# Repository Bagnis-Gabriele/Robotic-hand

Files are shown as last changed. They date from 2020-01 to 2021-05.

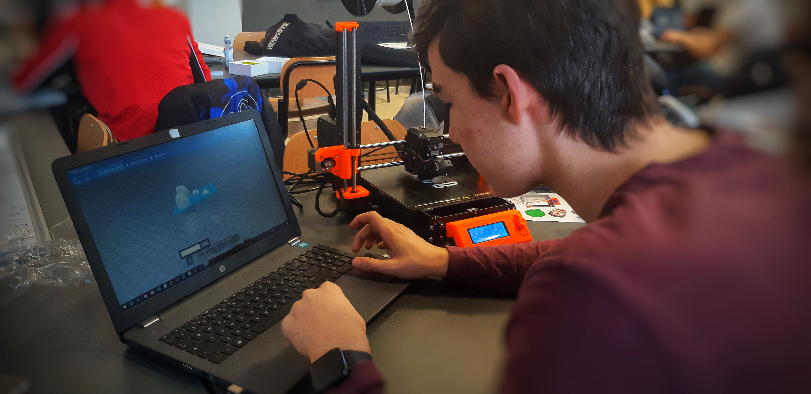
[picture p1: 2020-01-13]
photos/Team/Genovese.JPG

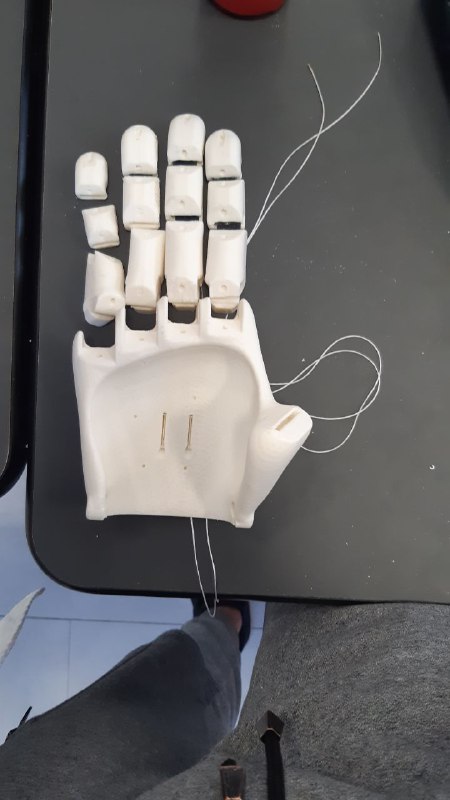
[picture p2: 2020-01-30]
photos/schemes/hand(no_thumb).jpg

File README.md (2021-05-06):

# Robotic-hand

### Project of Bagnis Gabriele, Bruno Luca, Cuniberti Andrea, Genovese Tommaso and Giavelli Luca.

* ### [Our Project](https://github.com/Bagnis-Gabriele/Robotic-hand/wiki/Our-Project#our-project)
* ### [Our Team](https://github.com/Bagnis-Gabriele/Robotic-hand/wiki/Our-Team#our-team)
* ### [Robotic Hand](https://github.com/Bagnis-Gabriele/Robotic-hand/wiki/The-Hand)
* ### [The Programs](https://github.com/Bagnis-Gabriele/Robotic-hand/wiki/The-Programs#the-programs)
* ### [The material](https://github.com/Bagnis-Gabriele/Robotic-hand/wiki/The-Materials)
* ### [How to use](https://github.com/Bagnis-Gabriele/Robotic-hand/wiki/How-to-use)

###### _We thank the Italian Institute of Technology of Genoa for providing us with the material and ideas and the ITIS Mario Delpozzo of Cuneo for helping us during this project._

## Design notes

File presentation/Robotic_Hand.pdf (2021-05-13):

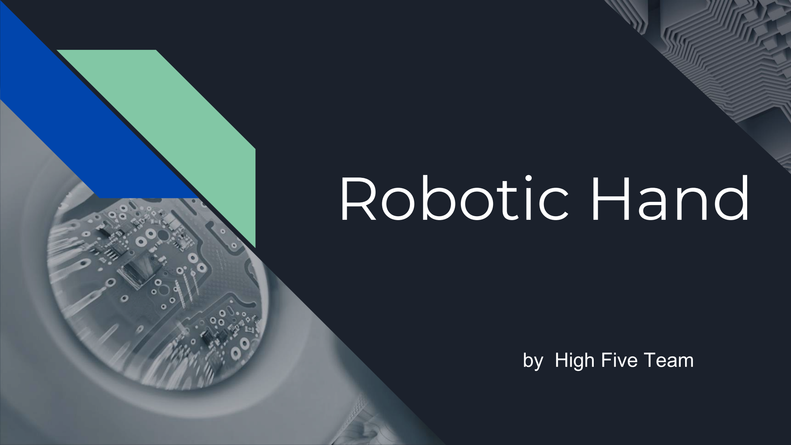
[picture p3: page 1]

# Robotic Hand

## by High Five Team

# Our project

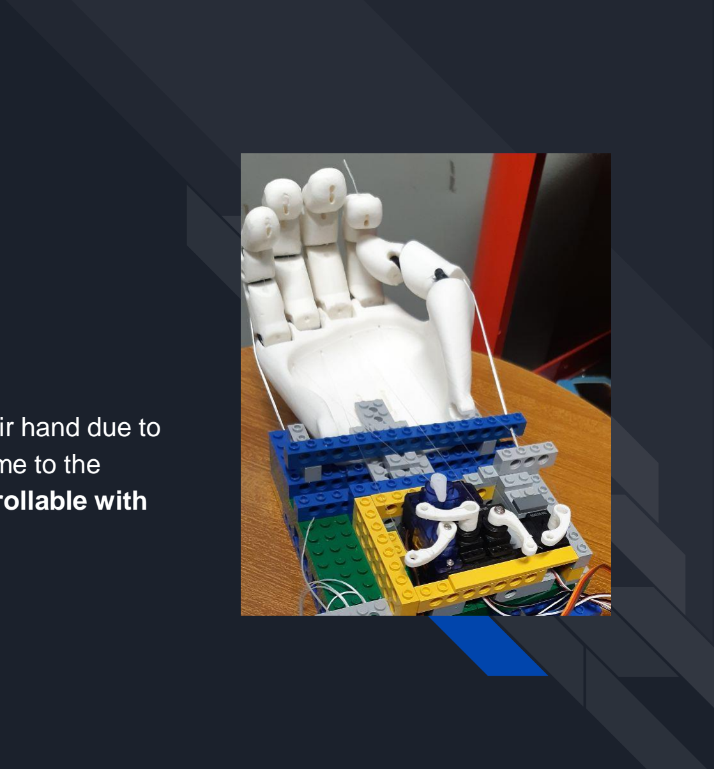
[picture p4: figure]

Our idea is to help people who have lost their hand due to accidents. After a long brainstorming we came to the conclusion of creating a robotic hand controllable with thought.

# Steps of the project

- The first step is to print a 3D robotic hand model and control it by Arduino.
- After printing the hand we move on to the second phase, where we reproduce the movements of the real hand on the robotic hand using the Leap sensor.
- Finally, we focused on the last phase and connected our robotic hand with the Emotiv and Muse sensor

# Steps of the project

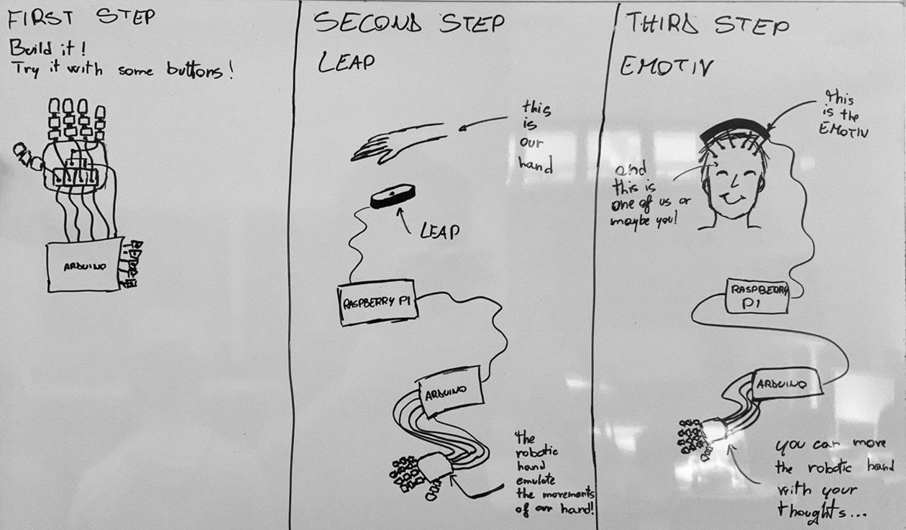
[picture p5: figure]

# The materials

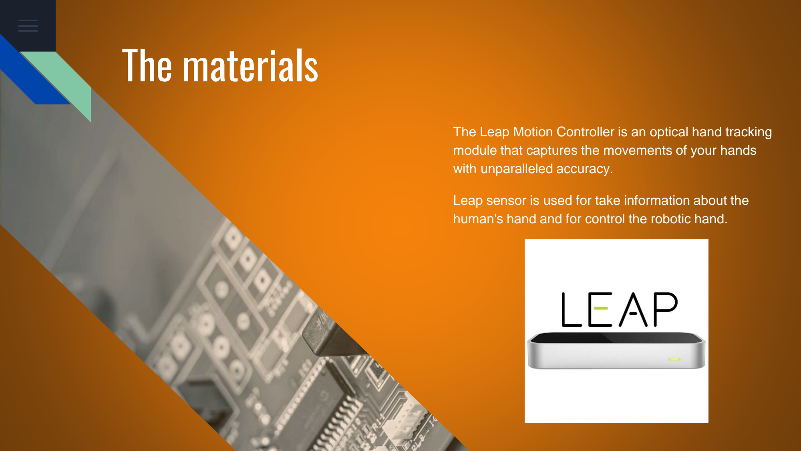
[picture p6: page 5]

The Leap Motion Controller is an optical hand tracking module that captures the movements of your hands with unparalleled accuracy.

Leap sensor is used for take information about the human's hand and for control the robotic hand.

# Emotiv

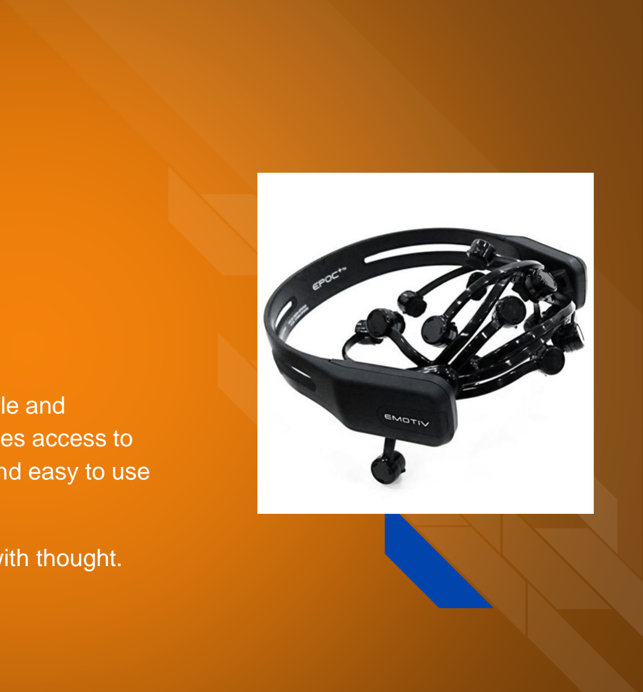
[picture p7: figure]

The EMOTIV EPOC+ is designed for scalable and contextual human brain research and provides access to professional grade brain data with a quick and easy to use design.

Emotiv is used for control the robotic hand with thought.

# Muse 2

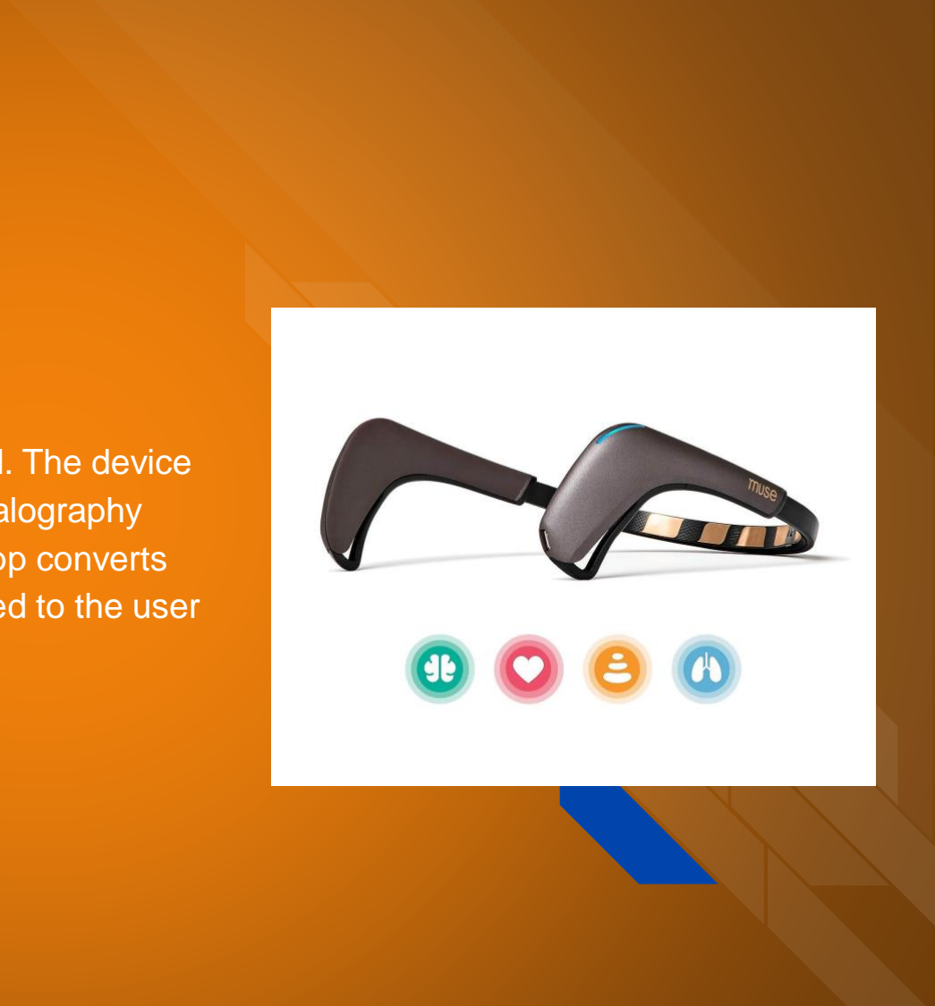
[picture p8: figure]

Muse is a wearable brain sensing headband. The device measures brain activity via 4 electroencephalography (EEG) sensors. An accompanying mobile app converts the EEG signal into audio feedback that is fed to the user via headphones.

# Arduino UNO

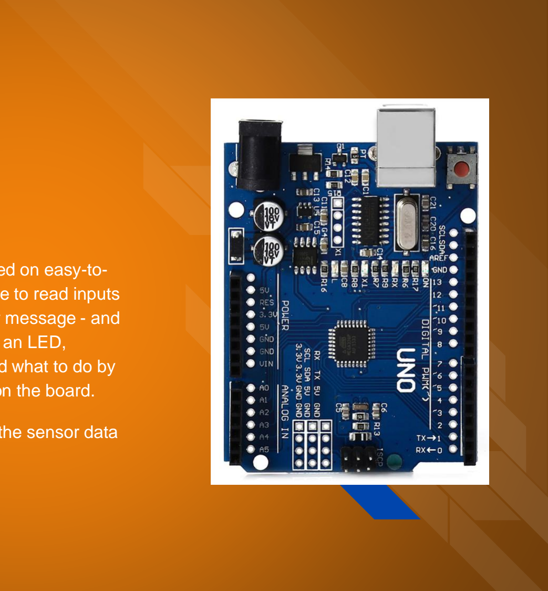
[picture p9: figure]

Arduino is an open-source electronics platform based on easy-touse hardware and software. Arduino boards are able to read inputs
- light on a sensor, a finger on a button, or a Twitter message - and turn it into an output - activating a motor, turning on an LED, publishing something online. You can tell your board what to do by sending a set of instructions to the microcontroller on the board.

Arduino is used to power the motors and based on the sensor data received, Arduino resets the various motors.

# Servo Motor

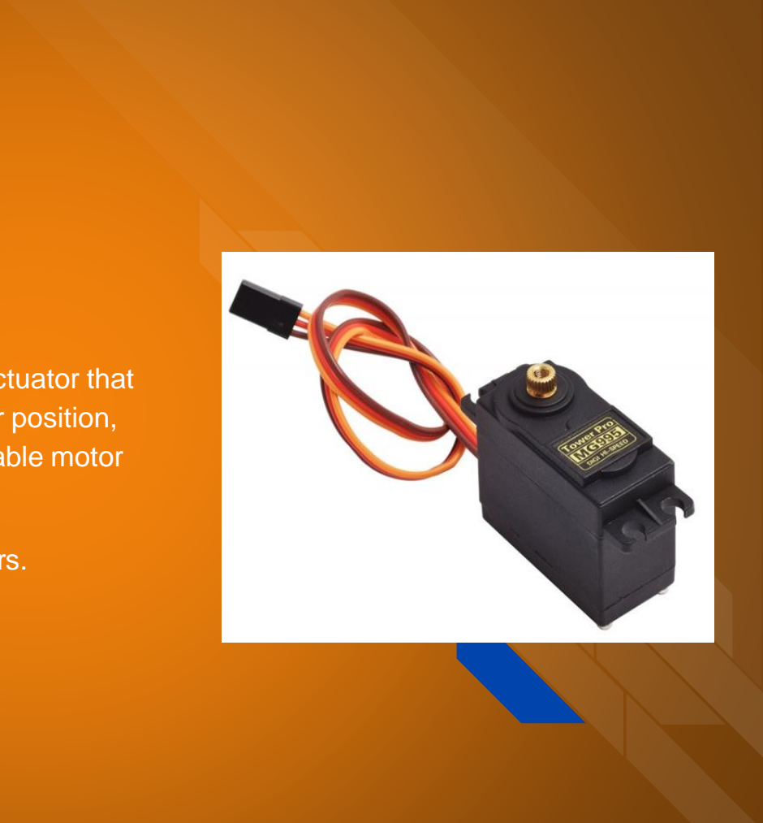
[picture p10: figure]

A servomotor is a rotary actuator or linear actuator that allows for precise control of angular or linear position, speed and acceleration. It consists of a suitable motor coupled to a sensor for position feedback.

We used these servomotor for moving fingers.

# 3D printer

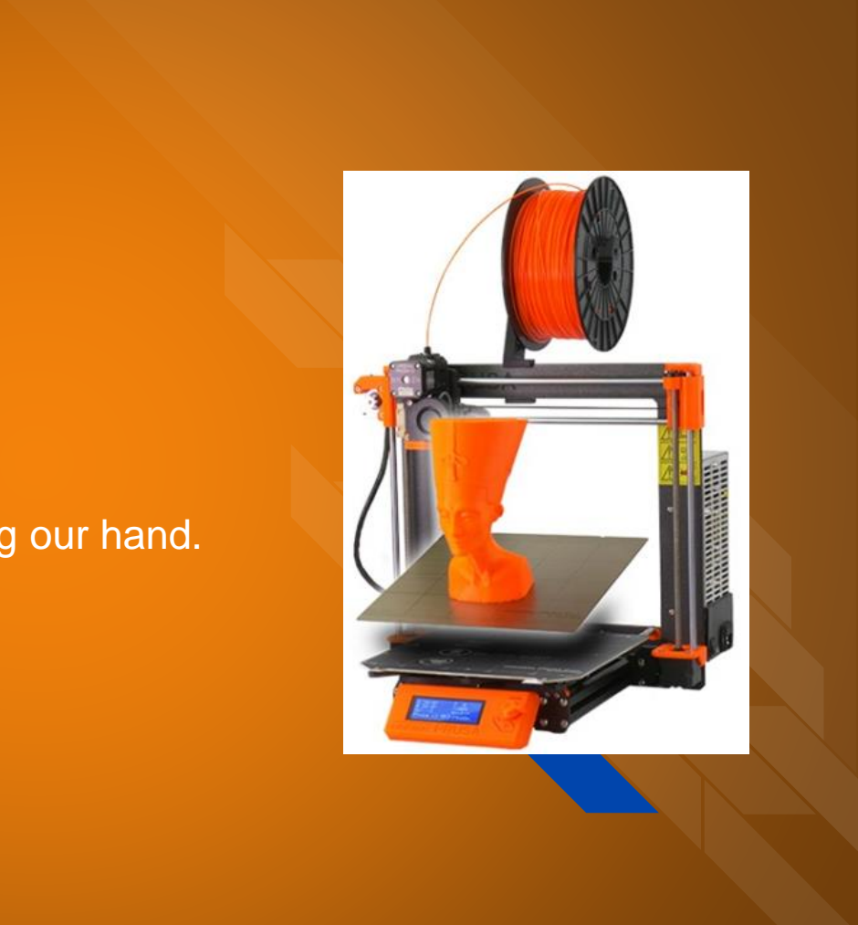
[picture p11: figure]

We used the 3D printer for creating our hand.

# History of the project

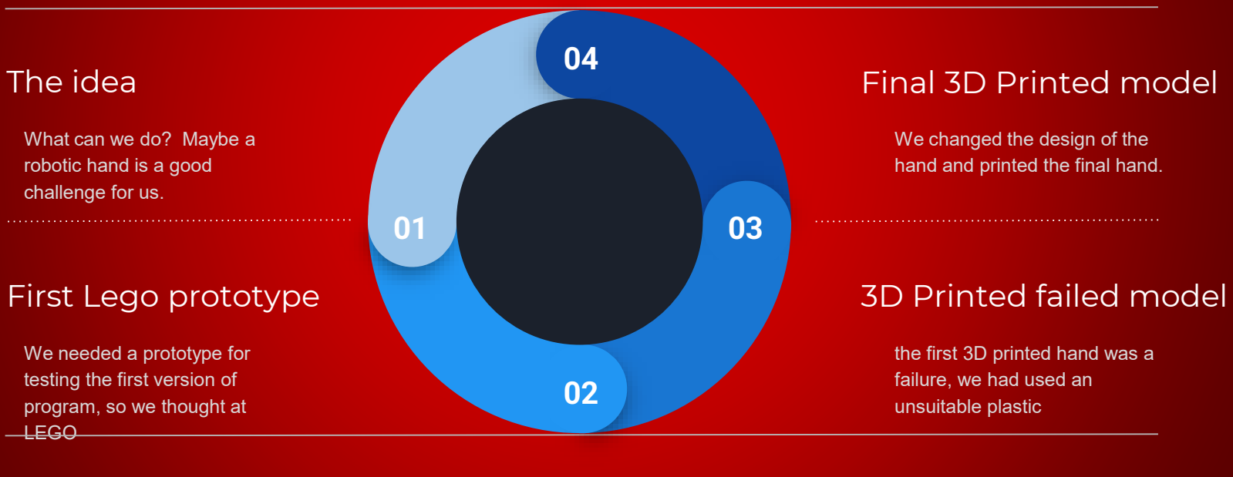
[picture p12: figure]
The idea; What can we do? Maybe a robotic hand is a good challenge for us.; First Lego prototype; We needed a prototype for testing the first version of program, so we thought at LEGO; Final 3D Printed model; We changed the design of the hand and printed the final hand.; 3D Printed failed model; the first 3D printed hand was a failure, we had used an unsuitable plastic

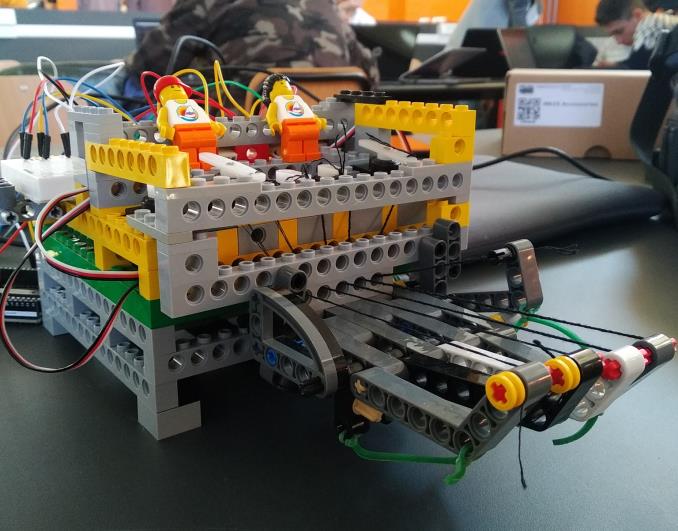
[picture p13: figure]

# First Lego prototype

# History of the project

We needed a reliable model to start testing the first versions of code while we were waiting for 3d printed one, so we thought we'd build it in LEGO technic bricks.

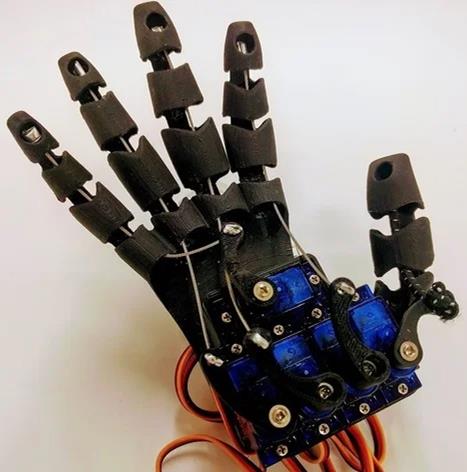
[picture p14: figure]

# 3D Printed failed model

# History of the project

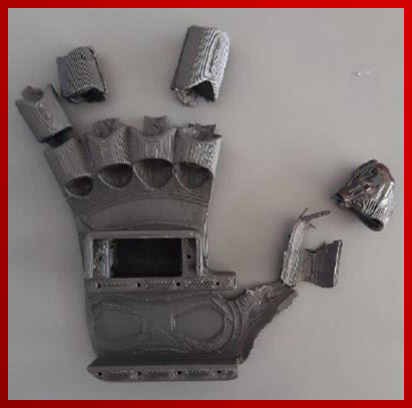
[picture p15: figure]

After some research we found an optimal prototype for our project, we printed it but the quality was not high and the material was not flexible enough.

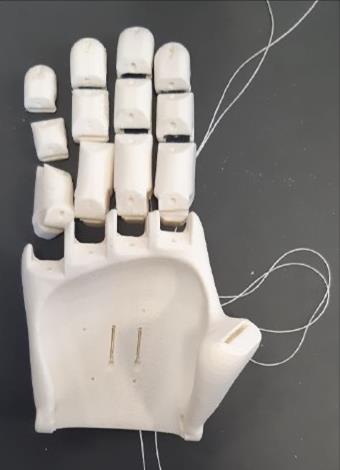
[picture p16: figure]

# Final 3D Printed model

# History of the project

Then we found another hand. Being the hand assemblable, we decide to try to print it in 3D only the thumb, with the appropriate joints and avoid wasting other material.

# The ForeArm

The last part of our project involved the construction of a wooden forearm that contained the servomotors, the remaining electrical component and allowed the movement of the wrist.

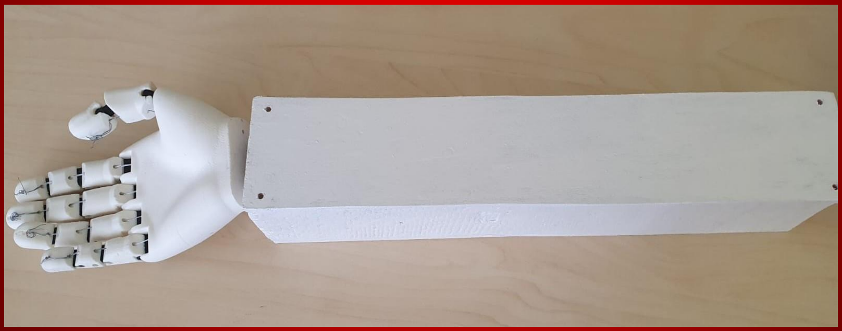
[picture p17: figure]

# The programs

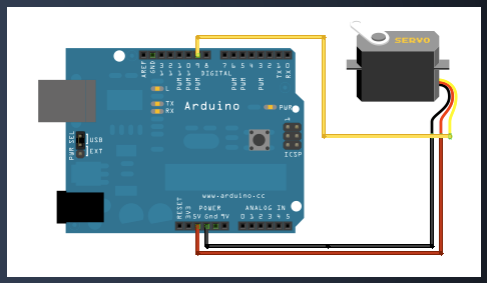
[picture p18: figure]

## We started with programming the Arduino to test the servomotors. (https://github.com/Bagnis-Gabriele/Robotic-hand)

# The programs

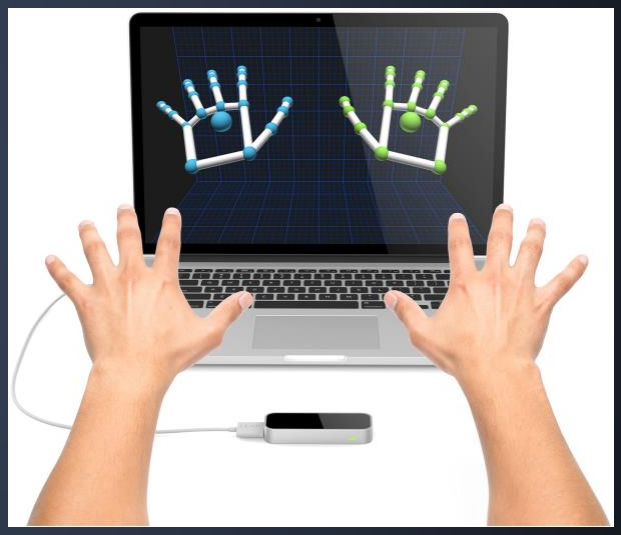
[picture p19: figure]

Then we developed a program to read data from the Leap, an infrared device that reads the positions of the several parts of the hand. At this point we encountered a problem: how to understand when the hand is open and when it is closed. We solved the problem by deciding to calculate the distance between the fingertip and the center of the hand. Shorter the distance is, closed the fingers are. (https://github.com/Bagnis-Gabriele/Robotic-hand)

# The programs

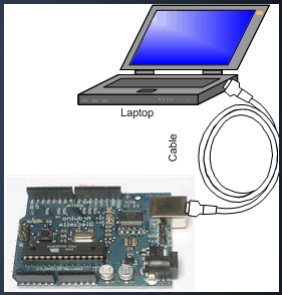
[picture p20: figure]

## Now we have to transmit this calculated data to Arduino: so we developed a communication protocol in python. (https://github.com/Bagnis-Gabriele/Robotic-hand)

# The programs

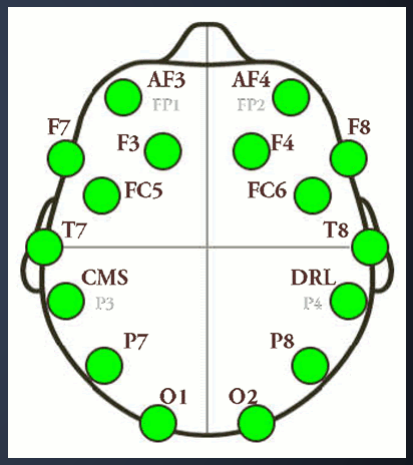
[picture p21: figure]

## After, we used the EPOC + programs and our protocol to allow control from the hand with the Emotiv, a helmet that recognizes the impulses that our neurons exchange. (https://github.com/Bagnis-Gabriele/Robotic-hand)

# The programs

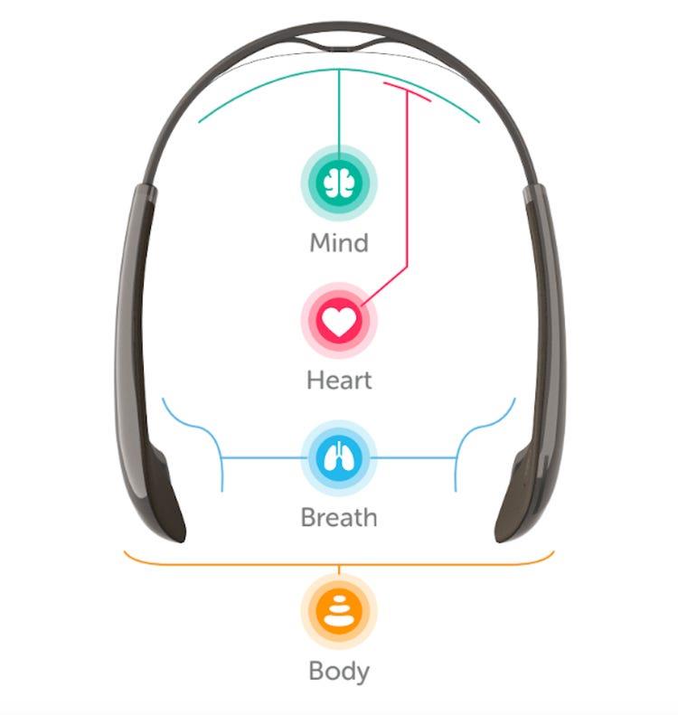
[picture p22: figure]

## Finally, we used Muse 2 to read the signals that swap neurons and analyze them.After training, the user can use his hand through thought. (https://github.com/Bagnis-Gabriele/Robotic-hand)

# The programs

You can visit our repo in github for downloading the code of our programs.

https://github.com/Bagnis-Gabriele/Robotic-hand

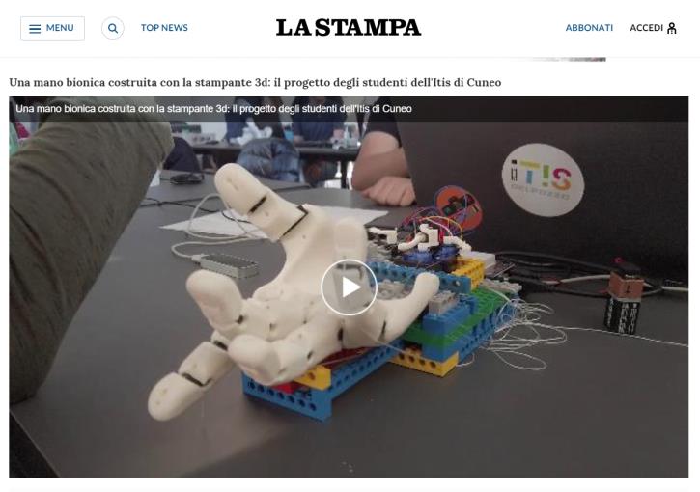
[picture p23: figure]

# Our project was as successful that we also gave a press interview:

## https://video.lastampa.it/cuneo/una -mano-bionica-costruita-con-lastampante-3d-il-progetto-deglistudenti-dell-itis-di-

cuneo/108755/108765 (https://video.lastampa.it/cuneo/una-mano-bionica-costruita-con-la-stampante-3d-il-progetto-degli-studenti-dell-itis-di-cuneo/108755/108765)

# Our success

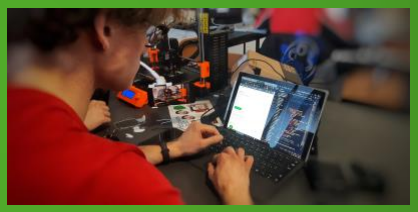
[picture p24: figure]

## Our team is made up of Bagnis Gabriele & Giavelli Luca, the programmers and Bruno Luca & Cuniberti Andrea & Genovese

Tommaso the technicians.

# Our team

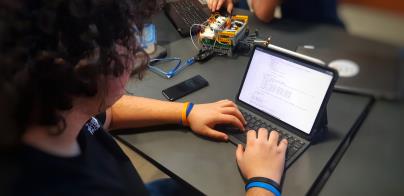
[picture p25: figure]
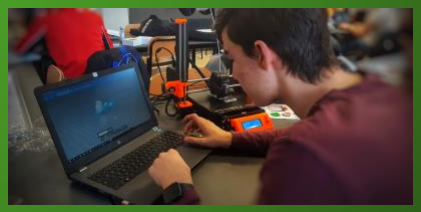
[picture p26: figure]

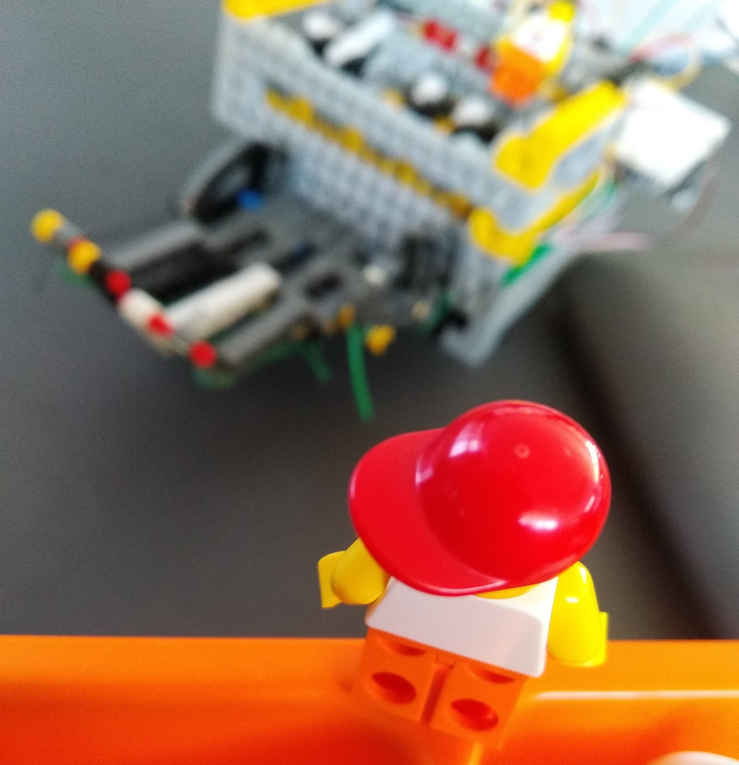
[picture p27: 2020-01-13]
photos/First_LEGO_prototype/image.jpg

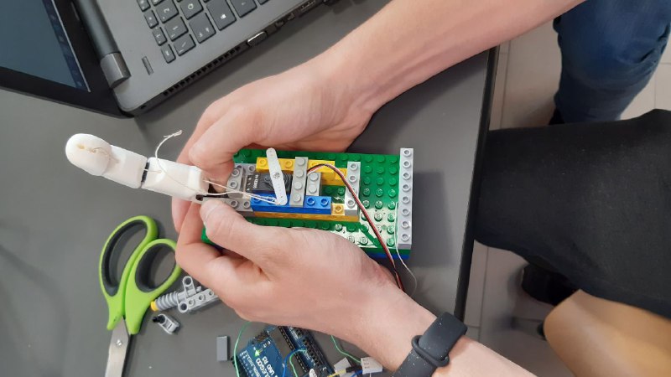
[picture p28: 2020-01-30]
photos/schemes/primoditoMotore.jpg

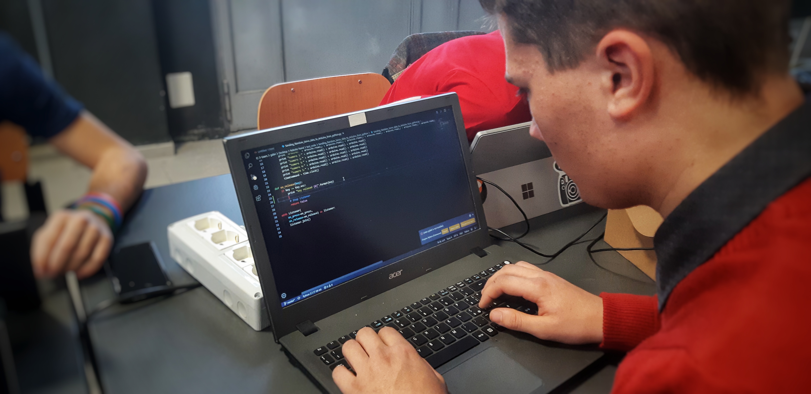
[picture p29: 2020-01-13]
photos/Team/Bagnis.JPG

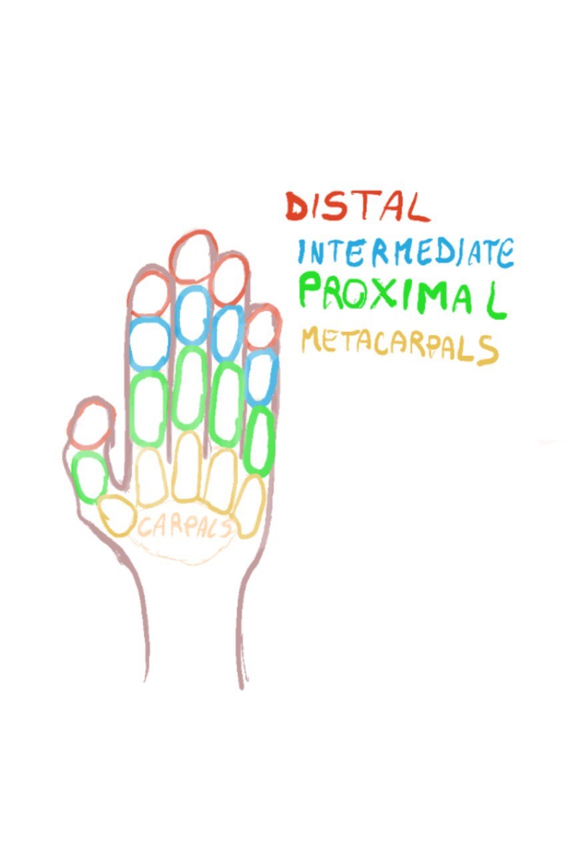
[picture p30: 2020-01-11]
photos/schemes/Bones.jpg

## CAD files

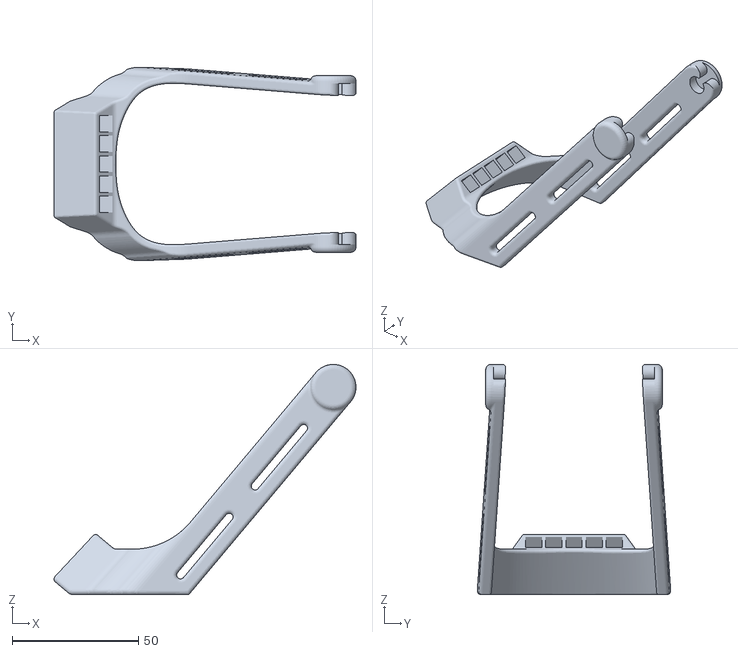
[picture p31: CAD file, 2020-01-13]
3d model/Gauntlet_-_Long.stl
119.7 x 76.7 x 91.2

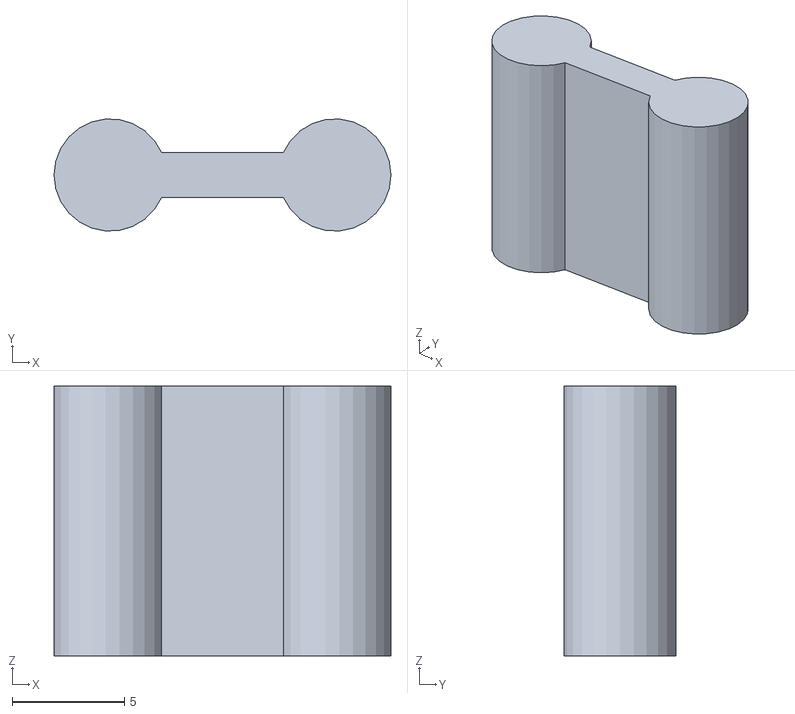
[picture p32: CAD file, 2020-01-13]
3d model/8.stl
15.0 x 4.98 x 12.0

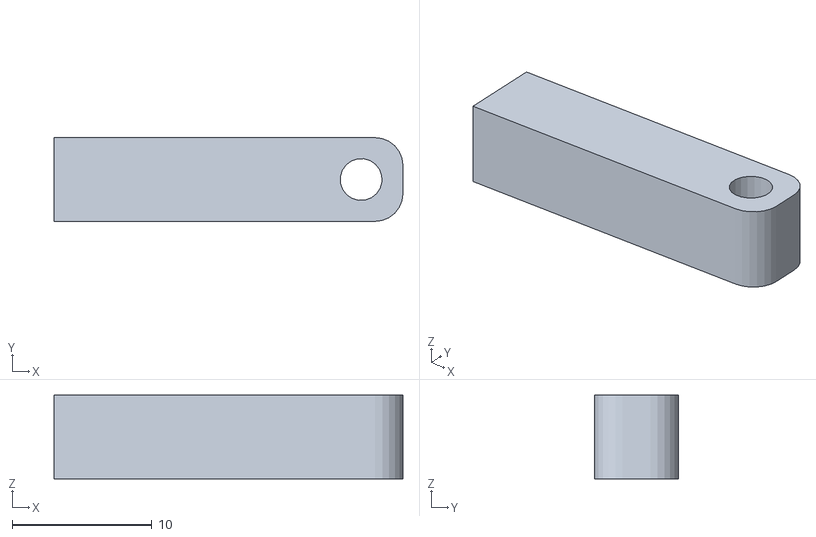
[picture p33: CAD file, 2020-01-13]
3d model/Tensioner.stl
25.0 x 6.00 x 6.00

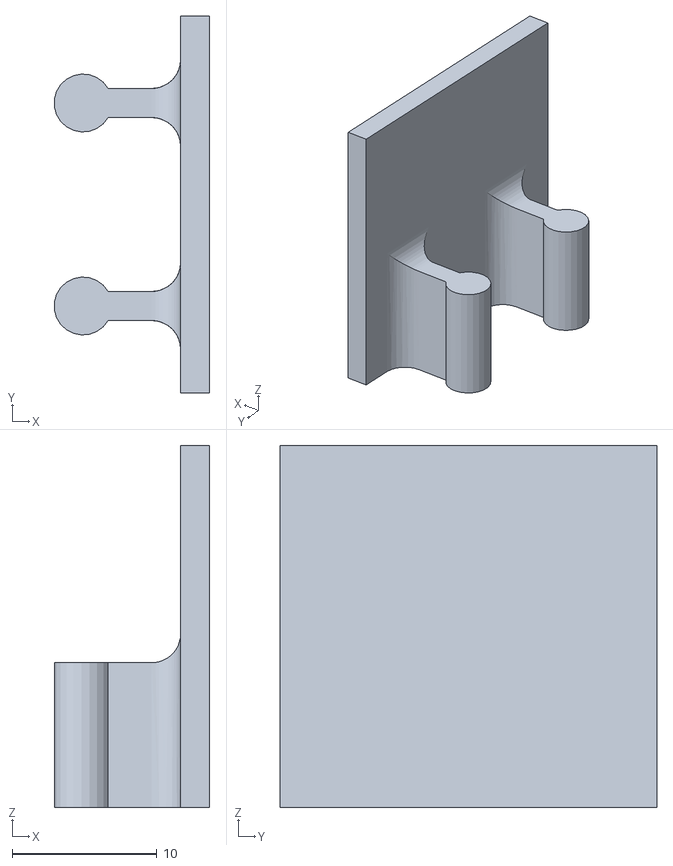
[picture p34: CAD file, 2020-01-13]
3d model/FFX_-_Bat_Connection_-_Orientation_1.stl
10.7 x 26.0 x 25.0

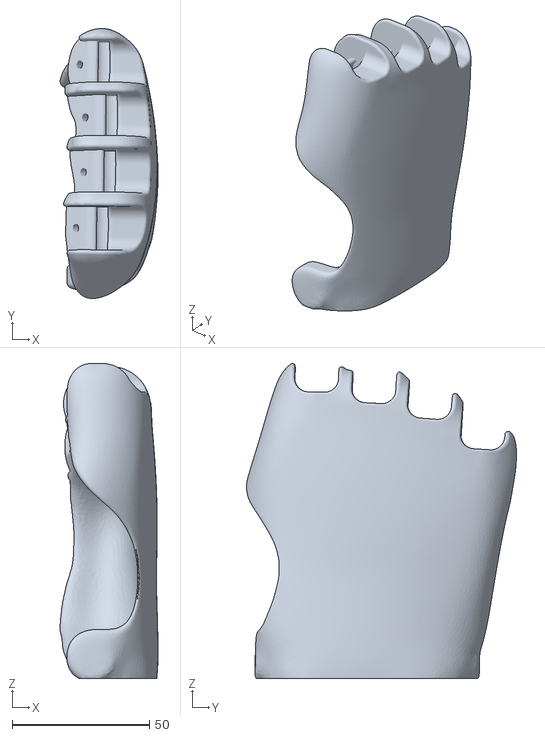
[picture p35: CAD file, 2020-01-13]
3d model/RH_Hand_Body_-_Wider_Wrist_-_No_Thumb.stl
35.7 x 98.3 x 114.7

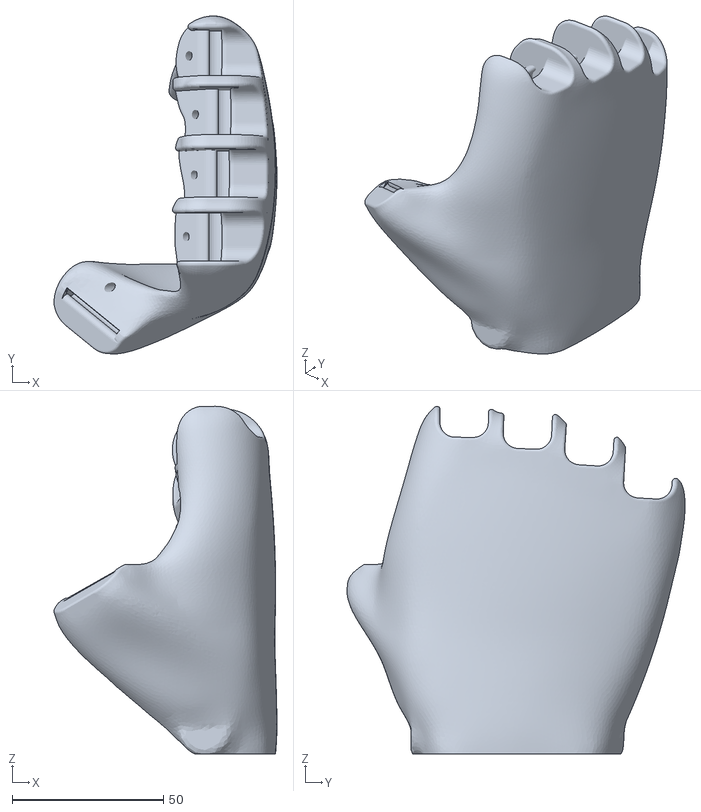
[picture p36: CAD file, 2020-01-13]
3d model/RH_Hand_Body.stl
73.7 x 111.7 x 114.9

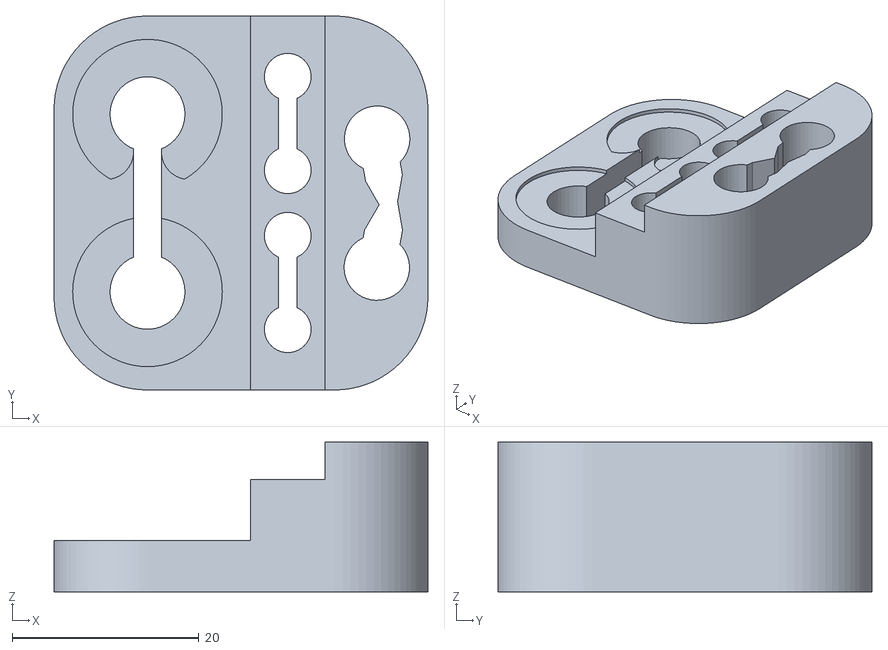
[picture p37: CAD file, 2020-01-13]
3d model/Mould.stl
40.0 x 40.0 x 16.0

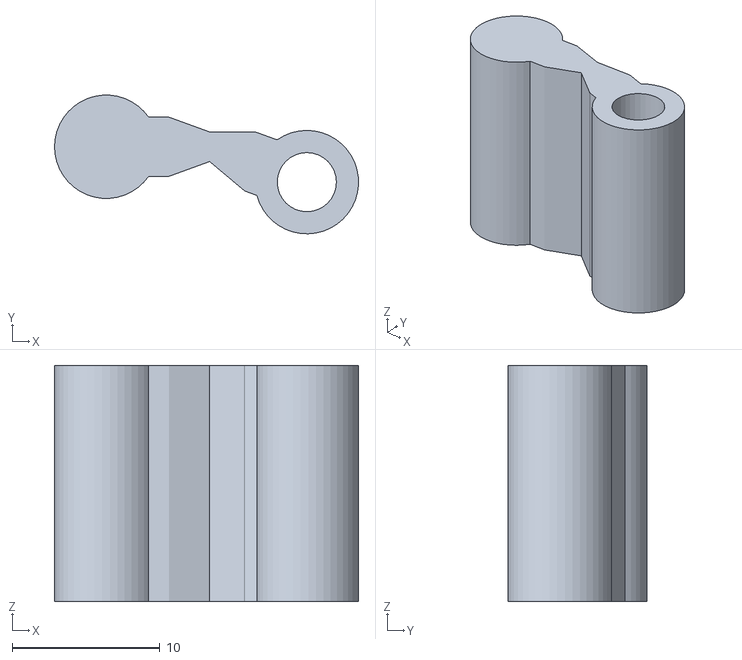
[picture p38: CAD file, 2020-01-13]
3d model/7.stl
20.6 x 9.38 x 16.0

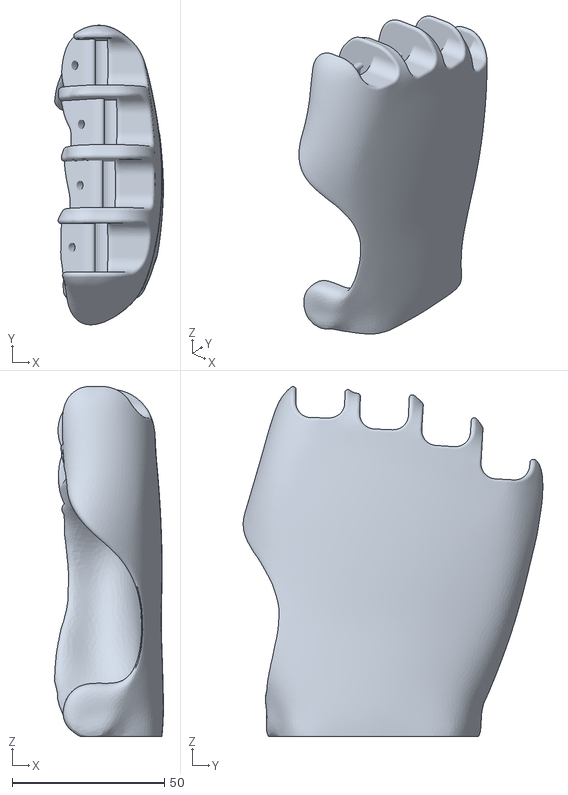
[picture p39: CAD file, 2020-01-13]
3d model/RH_Hand_Body_-_No_Thumb.stl
35.7 x 98.3 x 114.9

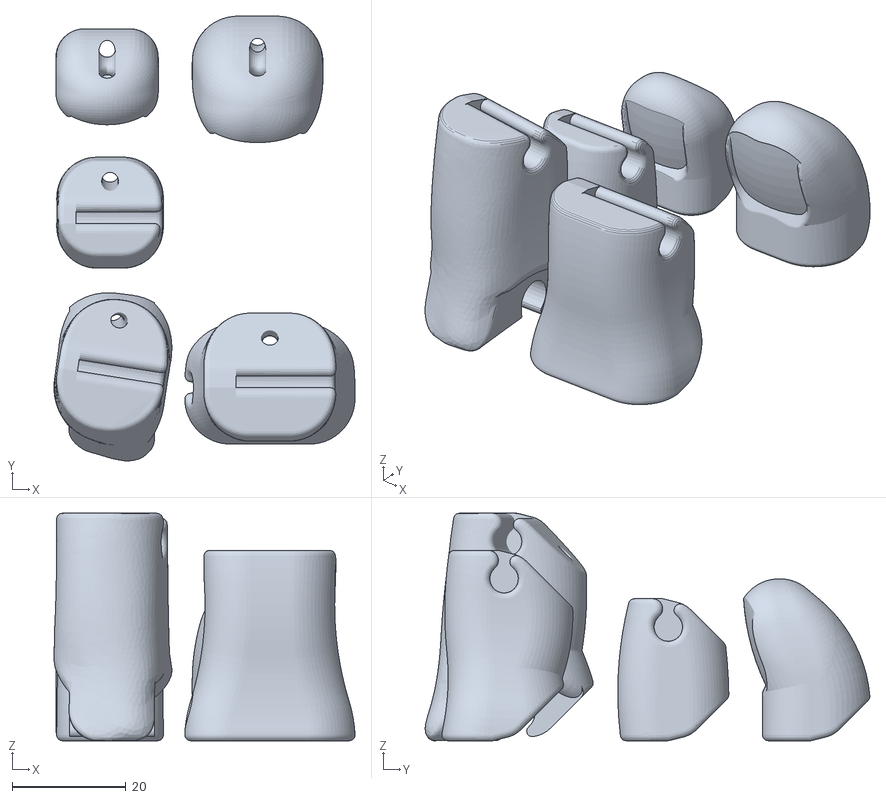
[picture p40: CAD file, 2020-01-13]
3d model/Indice_Pollice.stl
53.0 x 78.2 x 40.0

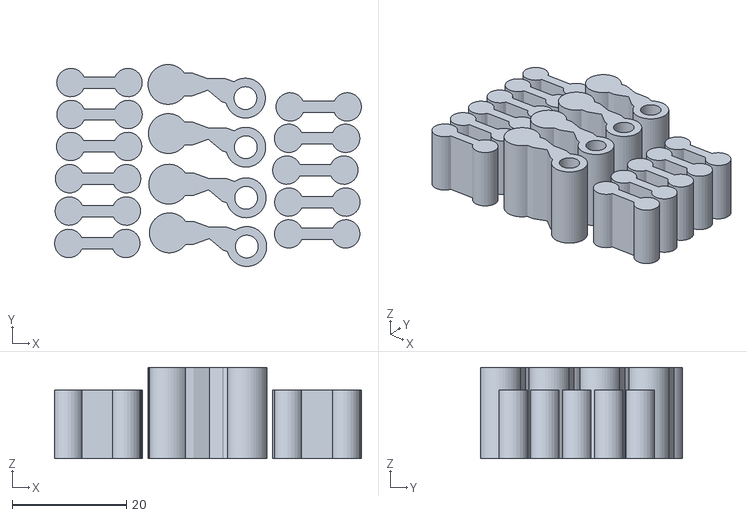
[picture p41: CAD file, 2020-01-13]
3d model/FFX_-_Finger_Hinge_Plate.stl
53.8 x 35.4 x 16.0

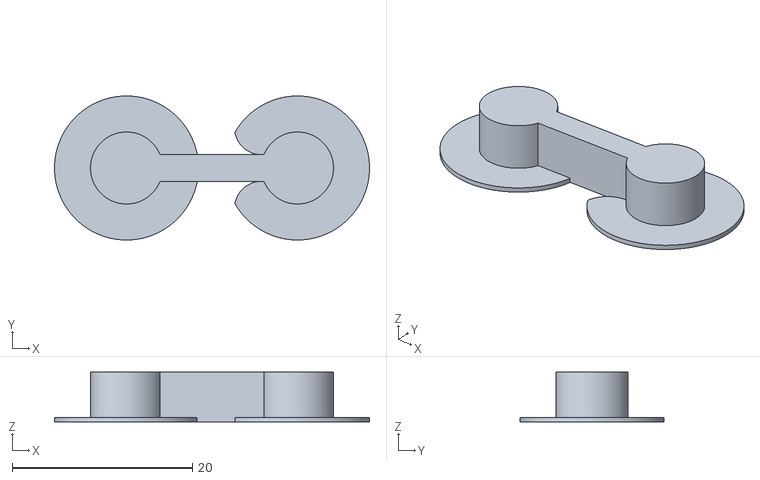
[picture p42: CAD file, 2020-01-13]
3d model/FFX_-_Flexy-Hinge_Wrist.stl
35.0 x 16.0 x 5.50

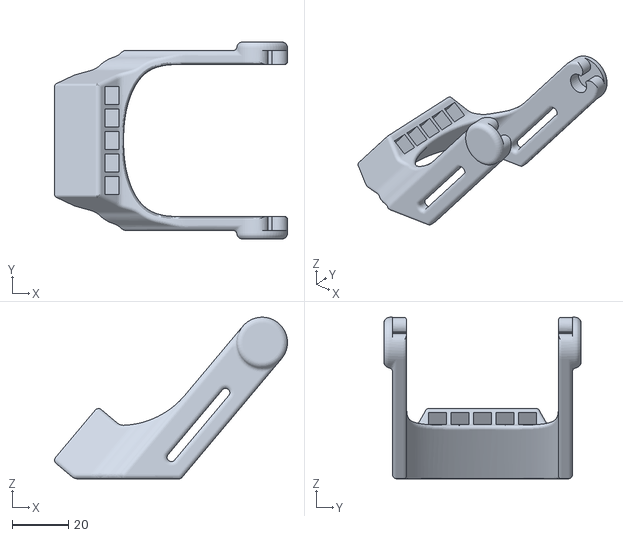
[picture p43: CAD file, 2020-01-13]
3d model/Gauntlet_-_Short.stl
82.8 x 70.0 x 57.4

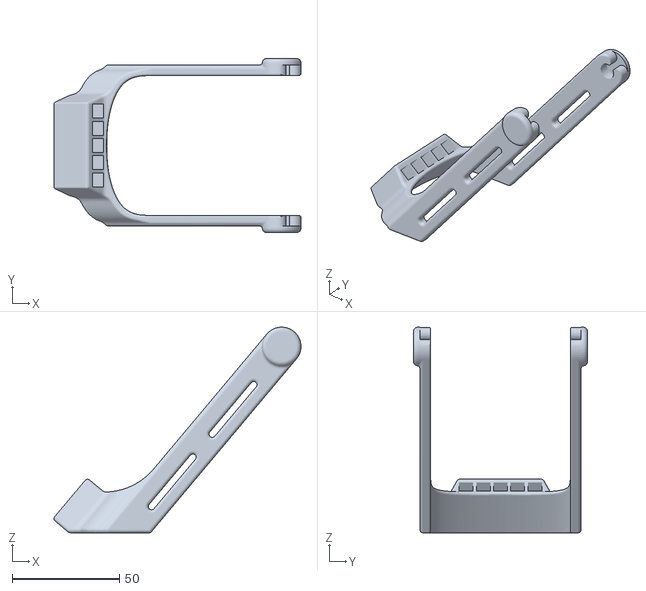
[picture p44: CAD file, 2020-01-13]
3d model/Gauntlet_-_Long_Wider_Wrist.stl
114.9 x 81.0 x 95.7

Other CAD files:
3d model/ThermoForm_Palm_Mesh_Wide_Wrist.stl
3d model/RH_Hand_Body_-_Wider_Wrist.stl
3d model/Gauntlet_-_Short_Wider_Wrist.stl
3d model/Flexy-Hand_2_Gauntlet_-_Thermoform.stl
3d model/RH_Hand_Body_-_Wider_Wrist_-_Opposable_Thumb.stl
3d model/ThermoForm_Palm_Mesh.stl
3d model/supportoServo(grandi) v5.f3d
3d model/supportoServo(grandi)v6.f3d

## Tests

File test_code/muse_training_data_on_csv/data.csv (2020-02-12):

delta | theta | alpha | beta | state
1.51609729335792 | 1.140497590424959 | 0.8288851765983194 | 0.8466766209785045 | O
1.4463867564027397 | 0.9184443732373265 | 0.9969240848106028 | 0.7498455033299768 | O
1.4840212216730335 | 0.7358047884217177 | 1.0921619172956663 | 0.9429057004281981 | O
1.379605307698358 | 1.1092514691446949 | 0.905480302135662 | 0.6850240828633192 | O
1.4414070381257766 | 1.146849838319001 | 0.881990643135799 | 0.7470453003209753 | O
1.5414419694369306 | 1.202432123952934 | 0.8395101701127214 | 0.7942247637977741 | O
1.508983120282947 | 1.1036812899616746 | 1.0050721220373644 | 0.8426589702054942 | O
1.4479255703861418 | 0.6661733705520668 | 0.9589375756313337 | 1.0030454331265521 | O
1.3450865264433278 | 1.081447787109424 | 0.9113704943997263 | 0.7092946994794097 | O
1.4865200060871742 | 1.1466443341852262 | 0.926178346717846 | 0.8273599580888533 | O
1.5308281754249338 | 1.1622561609022053 | 0.7916473898355745 | 0.7536366222200789 | O
1.5230578706386415 | 1.1584293370972578 | 0.84155164788696 | 0.8234382143187986 | O
1.454535287903881 | 0.8990174274622389 | 1.1499144169676967 | 0.8174082598162561 | O
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

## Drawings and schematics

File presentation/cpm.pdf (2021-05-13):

## 10 Giorni

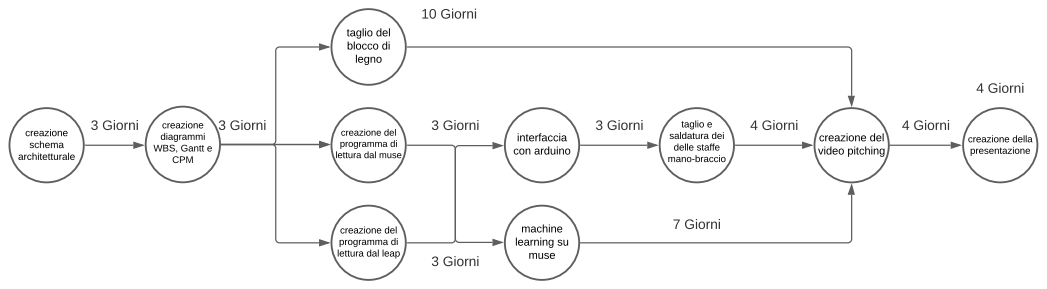
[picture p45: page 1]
creazione schema architetturale; taglio del blocco di legno; interfaccia con arduino; creazione del video pitching; creazione della presentazione; 3 Giorni; 7 Giorni; 4 Giorni

creazione
diagrammi
WBS, Gantt e CPM

taglio e
saldatura dei
delle staffe mano-braccio

creazione del
programma di
lettura dal muse

lettura dal leap

machine
learning su muse

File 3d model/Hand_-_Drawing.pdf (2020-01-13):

EXPLODED VIEW; PROXIMAL AND DISTAL INTERPHALANGEAL

BILL OF MATERIALS

ITEM NUMBER | DESCRIPTION | NUMBER OFF

1-1 | THUMB PROXIMAL PHALANX | 1
1-2 | THUMB DISTAL PHALANX | 1
2-1 | INDEX PROXIMAL PHALANX | 1
2-2 | INDEX MIDDLE PHALANX | 1
2-3 | INDEX DISTAL PHALANX | 1
3-1 | LONG PROXIMAL PHALANX | 1
3-2 | LONG MIDDLE PHALANX | 1
3-3 | LONG DISTAL PHALANX | 1
4-1 | RING PROXIMAL PHALANX | 1
4-2 | RING MIDDLE PHALANX | 1
4-3 | RING DISTAL PHALANX | 1
5-1 | SMALL PROXIMAL PHALANX | 1
5-2 | SMALL MIDDLE PHALANX | 1
5-3 | SMALL DISTAL PHALANX | 1
6 | HAND BODY | 1
7 | PALMAR DIGITAL | 4

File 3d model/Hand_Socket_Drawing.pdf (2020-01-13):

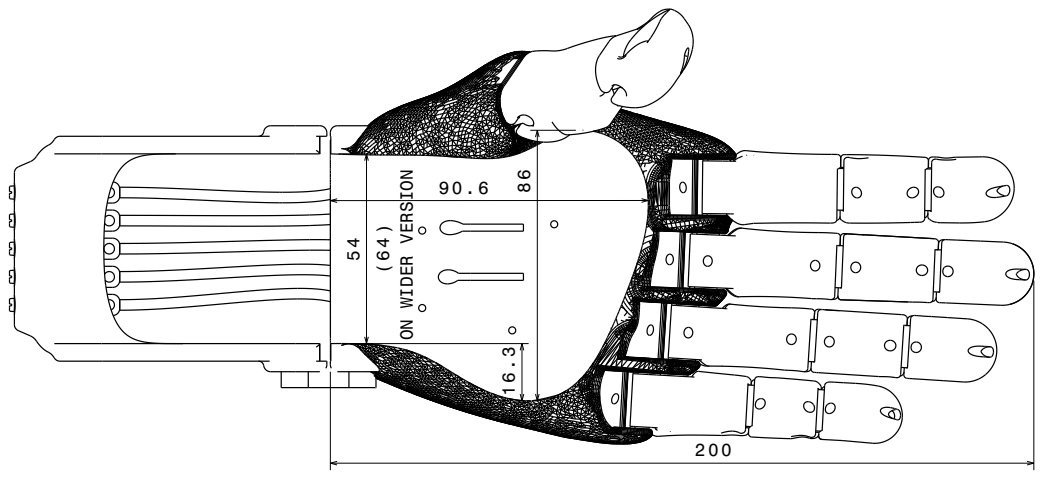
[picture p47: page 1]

ON WIDER VERSION

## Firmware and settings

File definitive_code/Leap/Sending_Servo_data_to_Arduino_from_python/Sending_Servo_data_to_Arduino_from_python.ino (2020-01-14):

#include<Servo.h>

//variables to transform the string into numbers
String msg;    //message sent from python
int number[5]; //vector for storing servo data
int power;     //exponentiation to calculate servo data
int k;         //counter
int pos;       //position to store the servo data

//servo pin
int s1 = 5;
int s2 = 6;
int s3 = 7;
int s4 = 8;
int s5 = 9;

//servo objects
Servo m1;
Servo m2;
Servo m3;
Servo m4;
Servo m5;

void setup() {
  //select the servo pin
  m1.attach(s1);
  m2.attach(s2);
  m3.attach(s3);
  m4.attach(s4);
  m5.attach(s5);
  
  //initialize the serial port
  Serial.begin(9600);
  
  //servo reset
  m1.write(180);
  m2.write(180);
  m3.write(180);
  m4.write(180);
  m5.write(180);
}

void loop(){
  
  //if there is data avaible read it
  if(Serial.available()){
    
    //read message
    msg = Serial.readString();

    //vector reset
    for (k=0;k<5;k++){
      number[k]=0;
    }

    //Servo data calculation
    for (k=0; k<15; k++){
      //position setting
      switch (k){
        case 0: case 1: case 2: pos=0; break;
        case 3: case 4: case 5: pos=1; break;
        case 6: case 7: case 8: pos=2; break;
        case 9: case 10: case 11: pos=3; break;
        case 12: case 13: case 14: pos=4; break;
      }
      //pow setting
      switch (k){
        case 0: case 3: case 6: case 9: case 12: power=100; break;
        case 1: case 4: case 7: case 10: case 13: power=10; break;
        case 2: case 5: case 8: case 11: case 14: power=1; break;
      }
      //sum of the number
      number[pos]+=(((int)msg.charAt(k))-48)*power;
    }

    m1.write(number[0]);
    m2.write(number[1]);
    m3.write(number[2]);
    m4.write(number[3]);
    m5.write(number[4]);

    Serial.print(1);
  }
}

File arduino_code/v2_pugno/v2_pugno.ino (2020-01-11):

#include<Servo.h>

#define FINGERS 5
#define MAX_DEGREE 180

//servo pin
int s1 = 5;
int s2 = 6;
int s3 = 7;
int s4 = 8;
int s5 = 9;

//servo objects
Servo m1;
Servo m2;
Servo m3;
Servo m4;
Servo m5;

//servo degree position
int p1 = 0;
int p2 = 0;
int p3 = 0;
int p4 = 0;
int p5 = 0;

void setup() {
  //select the servo pin
  m1.attach(s1);
  m2.attach(s2);
  m3.attach(s3);
  m4.attach(s4);
  m5.attach(s5);
  Serial.begin(9600);

  m1.write(180);
  m2.write(180);
  m3.write(180);
  m4.write(180);
  m5.write(0);

  delay(2000);
}

void loop(){
  
  /*close
  for(int k=0; k<MAX_DEGREE; k+=5){
    //increment all servos dergees
    p1 += 5;
    p2 += 5;
    p3 += 5;
    p4 += 5;
    p5 += 5;

    //renew servos position
    m1.write(p1);
    m2.write(p2);
    m3.write(p3);
    m4.write(p4);
    m5.write(p5);

    //delay(4);

    Serial.println(p1);
    Serial.println(p2);
    Serial.println(p3);
    Serial.println(p4);
    Serial.println(p5);
  }

  //open
  for(int k=0; k<MAX_DEGREE; k+=5){
    //increment all servos dergees
    p1 -= 5;
    p2 -= 5;
    p3 -= 5;
    p4 -= 5;
    p5 -= 5;

    //renew servos position
    m1.write(p1);
    m2.write(p2);
    m3.write(p3);
    m4.write(p4);
    m5.write(p5);

    //delay(4);

    Serial.println(p1);
    Serial.println(p2);
    Serial.println(p3);
    Serial.println(p4);
    Serial.println(p5);
  }
  */
}

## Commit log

2020-01-09 addition of the 3d model of the hand
    [SG92R_ServoHone_11.STL, SG92R_ServoHone_5.STL]
2020-01-09 Button Control
    Created a file that let control the hand with 2 buttons for each fingers, still have to test it ASAP
2020-01-09 Fist scketch
    Fixed fist program, need to test before usage
    [v2_pugno.ino]
2020-01-10 Comunication between arduino and leap
    v3 program let arduino comunicate with leap motion sensor, adjusted v2 program, now work perfeclty
2020-01-10 Reorganization of the repository
    [SG92R_ServoHone_11.STL, SG92R_ServoHone_5.STL]
2020-01-10 Reorganization of the repository and loading of the code to make python communicate with arduino
    [SG92R_ServoHone_11.STL, SG92R_ServoHone_5.STL]
2020-01-13 First LEGO prototype.
    We built the first prototype of our robotic hand with LEGO!
2020-01-13 Revert "First LEGO prototype."
    This reverts commit df6c4dc44353dfcaf739ca20929d1da993d44c59.
2020-01-13 First_LEGO_prototype
    We built the first prototype of robotic hand with LEGO!
2020-01-14 Touch implementation
    First version, need to delete laste part and decomment all loop function when all fingers will be printed and assembled
2020-02-01 Hand: support for the engines
    [supportoServo(grandi) v5.f3d, supportoServo(grandi)v6.f3d]
2020-02-12 add muse program
    [data.csv]
